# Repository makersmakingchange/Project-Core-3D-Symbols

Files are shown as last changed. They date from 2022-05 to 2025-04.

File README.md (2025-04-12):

# Project Core 3D Symbols
The Project Core 3D symbols consists of a set of 3D printable three-dimensional (3D) symbols that represent 36 words in the Universal Core vocabulary. The word category is indicated with the shape, texture, and color of the base. The individual word is indicated with a unique raised element, the printed word, and the word in Braille. This repository contains a copy of Version 4, last updated January 2020. For instructions on how to introduce and use these symbols, refer to the original site: http://www.project-core.com/3d-symbols/   

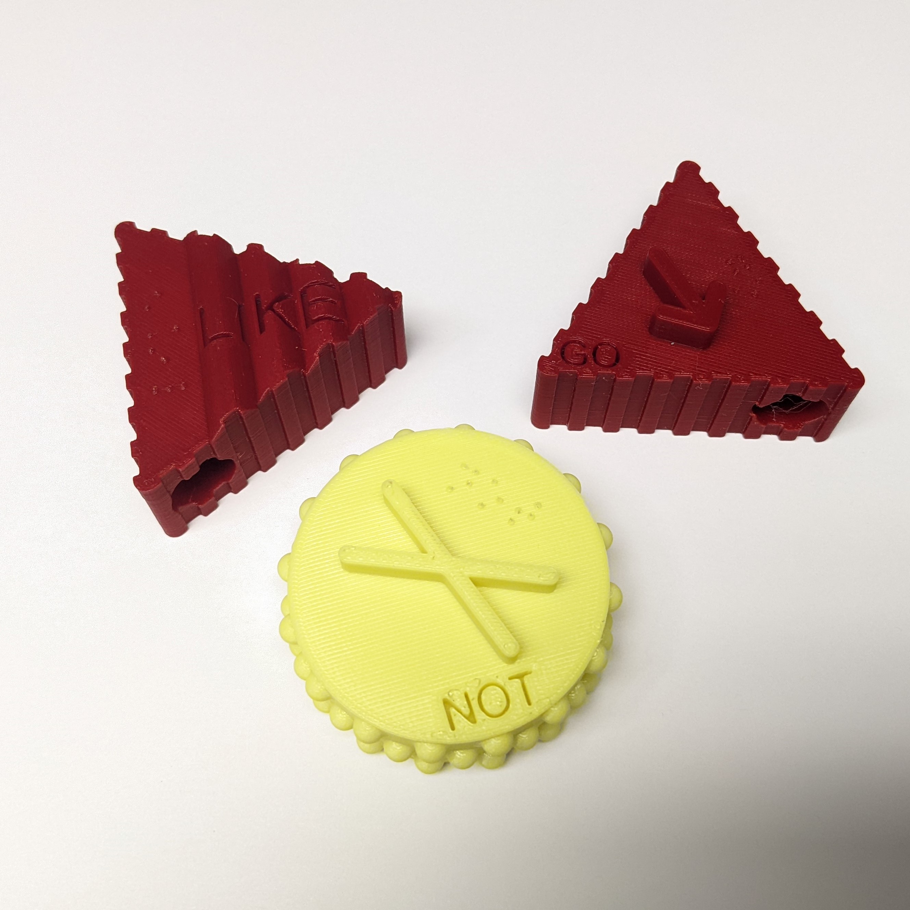
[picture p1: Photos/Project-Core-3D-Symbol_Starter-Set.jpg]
Picture of three 3D printed tactile symbols. There are three symbols, a triangular red 'Go', a triangular red 'Like', and a circular yellow 'Not'.


| **Word Class** | **Shape** | **Edge Texture** | **Color** |
|:---:|:---:|:---:|:---:|
| adverb | circle  | bumps (reverse golf ball dimples) | yellow  |
| adjective | heart | smooth | blue |
| pronoun |  hexagon  | cross hatch | white |
| preposition  | square  | horizontal grooves | green |
| verb |  triangle | vertical ridges like a quarter | red |
| noun | trapezoid | horizontal wavy grooves | orange  |
|  interjection  |  pentagon | single string of bumps (string of pearls) | black |

## More info at
- [Project Core](http://www.project-core.com/)
- [Project Core 3D Symbols](http://www.project-core.com/3d-symbols)
- [Project Core 3D Symbol - Use Instructions](http://www.project-core.com/3d-symbols-use/)
- [Makers Making Change Project Page](https://makersmakingchange.com/project/project-core-3d-symbols/)

## Getting Started

### 1. Determine which symbols are required
Refer to the usage guide and/or consult with the user to determine which of the symbols are required.

### 2. 3D Print the Symbols
All of the individual print files are in the [/Build_Files/3D_Print_Files](/Build_Files/3D_Print_Files/) folder.
Note that depending on the word class, there are 7 different intended colors of filament. The starter set (GO, LIKE, NOT) requires two filament colors: yellow and red. If printed in the intended colors, the full set of 36 requires 5 filament colors: yellow, blue, white, green, and red.

## Files
### Documentation
| Document | Version | Link |
|---|---|---|
| Bill of Materials | 1.0 | [Project-Core-3D-Symbols_Bill_of_Materials](/Documentation/Project-Core-3D-Symbols_BOM_V1.0.xlsx) |
| Maker Checklist | 1.0 | [Project-Core-3D-Symbols_Maker_Checklist](/Documentation/Project-Core-3D-Symbols_Maker_Checklist_V1.0.pdf) |
| User Guide | 09.25.17 | [Project-Core-3D-Symbols_Use](/Documentation/Project-Core-3D-Symbols_Use_09.25.17.pdf) |
| Changelog | 1.0 | [Project-Core-3D-Symbols_Changelog](/Documentation/Project-Core-3D-Symbols_Changelog_V1.0.pdf) |

### Design Files
Unfortunately, the original design files are not available for this project.

### Build Files
 - [3D Print Files](/Build_Files/3D_Print_Files)

 Note: The original filenames have been changed to the following format: WORD_COLOR_VERSION.stl. This should make it easier to print the symbols in the intended color if so desired.

## Attribution
The 3D Universal Core Vocabulary Symbols were designed by [The Center for Literacy and Disability Studies](http://www.project-core.com/3d-symbols/).

The Bill of Materials and the 3D Printing Guide were created by Neil Squire / Makers Making Change. 

## License


The 3D Universal Core Vocabulary Symbols by [The Center for Literacy and Disability Studies](https://www.project-core.com/3d-symbols/) are licensed under a [Creative Commons Attribution 4.0 International License](https://creativecommons.org/licenses/by/4.0/).

----
<!-- ABOUT MMC START -->
## About Makers Making Change
[Makers Making Change Logo](https://www.makersmakingchange.com/)

Makers Making Change is a program of [Neil Squire](https://www.neilsquire.ca/), a Canadian non-profit that uses technology, knowledge, and passion to empower people with disabilities.

Makers Making Change leverages the capacity of community based Makers, Disability Professionals and Volunteers to develop and deliver affordable Open Source Assistive Technologies.

 - Website: [www.MakersMakingChange.com](https://www.makersmakingchange.com/)
 - GitHub: [makersmakingchange](https://github.com/makersmakingchange)
 - Bluesky: [@makersmakingchange.bsky.social](https://bsky.app/profile/makersmakingchange.bsky.social)
 - Instagram: [@makersmakingchange](https://www.instagram.com/makersmakingchange)
 - Facebook: [makersmakechange](https://www.facebook.com/makersmakechange)
 - LinkedIn: [Neil Squire Society](https://www.linkedin.com/company/neil-squire-society/)
 - Thingiverse: [makersmakingchange](https://www.thingiverse.com/makersmakingchange/about)
 - Printables: [MakersMakingChange](https://www.printables.com/@MakersMakingChange)

### Contact Us
For technical questions, to get involved, or to share your experience we encourage you to [visit our website](https://www.makersmakingchange.com/) or [contact us](https://www.makersmakingchange.com/s/contact).
<!-- ABOUT MMC END -->

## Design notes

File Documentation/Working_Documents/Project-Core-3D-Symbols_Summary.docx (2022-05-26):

# Title

## Project Core 3D Symbols

## Subtitle

A set of 3d printable tactile representations of Universal Core Vocabulary

## Device Specifications

Designer: Center for Literacy and Disability Studies

Build Time: 1-4 hr

Cost: $6-$20

Stage: User Tested

Skills Required: 3D Printing

Disability Type: Visual, Cognitive/Learning

Difficulty: Beginner

Time to Complete: 1-4 hr, >10 hour

License: Attribution 4.0 International

Usage: Communication Aids (AAC)

Type: n/a

## Device Details

### Overview

The Project Core 3D symbols are a set of 3D printable three-dimensional (3D) symbols that represent words in the Universal Core vocabulary (https://www.med.unc.edu/ahs/clds/universal-core-vocabulary/). The Universal Core vocabulary is ‘a set of 36 highly useful single words that can be used alone or in combination to communicate for a range of purposes on countless topics with a wide variety of communication partners.’

For the 3D symbols, the individual word is indicated with a unique raised element, the printed word, and the word in Braille. The word category is indicated with the shape, texture, and color of the base.

Project Core also provides the symbols in different formats.

### Usage

These symbols may be useful to help students with visual impairments and/or significant cognitive impairments communicate. For instructions on how to introduce and use these symbols, refer to the original site: http://www.project-core.com/3d-symbols/

### Cost

Each symbol requires less than $1 of plastic. The cost of materials for the three starter symbols is about $1.50. A full set requires $18 worth of plastic. The total cost to produce these may be increased if the different colors are required. (A 1 kg roll of filament is typically $25-35)

### Build Instructions

Each symbol is 3D printed. The files can be found at the linked GitHub repository or on the original site.

#### Skills Required

- 3D printing

#### Time Required

Each symbol takes approximately 2 hours to 3D print on its own. A total set may then take up to 73 hours to print.

#### 3D Printing

The symbols are a simple print and do not require support. Refer to the 3D Printing Guide for instructions. Multiple symbols of the same color may be printed at the same time. The red symbols may require two setups.

### Attribution

The 3D Universal Core Vocabulary Symbols were designed by [The Center for Literacy and Disability Studies](http://www.project-core.com/3d-symbols/).

The Bill of Materials and the 3D Printing Guide were created by Neil Squire / Makers Making Change.

## Project Core 3D Symbols

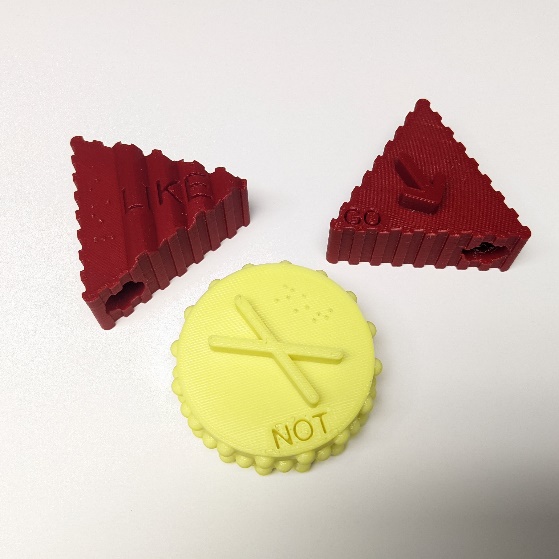
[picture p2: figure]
Picture of three 3D printed tactile symbols. There are three symbols, a triangular red "Go", a triangular red "Like", and a circular yellow "Not".

MMC Library Link:

https://makersmakingchange.com/project/project-core-3d-symbols/

### Overview

The Project Core 3D symbols are a set of 3D printable three-dimensional (3D) symbols that represent words in the Universal Core vocabulary (https://www.med.unc.edu/ahs/clds/universal-core-vocabulary/). The Universal Core vocabulary is ‘a set of 36 highly useful single words that can be used alone or in combination to communicate for a range of purposes on countless topics with a wide variety of communication partners.’

For the 3D symbols, the individual word is indicated with a unique raised element, the printed word, and the word in Braille. The word category is indicated with the shape, texture, and color of the base.

Project Core also provides the symbols in different formats.

### Usage

These symbols may be useful to help students with visual impairments and/or significant cognitive impairments communicate. For instructions on how to introduce and use these symbols, refer to the original site: http://www.project-core.com/3d-symbols/

© 2022 by Neil Squire. This work is licensed under the CC BY 4.0 License: http://creativecommons.org/licenses/by/4.0 Files available at https://makersmakingchange.com/project/project-core-3d-symbols/ Page 1 of 2

V4 | MAY 2022 Project Core 3D Symbols Summary

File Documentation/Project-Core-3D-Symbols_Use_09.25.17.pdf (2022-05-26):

The following provides initial guidance to school teams on how to introduce and use the 3D symbols. This document will continue to be revised as a result of ongoing research to further define effective practices. Please visit www.project-core.com for the latest version.

© 2016 University of North Carolina at Chapel Hill, The Center for Literacy and Disability Studies www.project-core.com
draft date: 09/25/2017

### 3D Symbol Core Sandwich – GO

First:
Recognize that an activity involves movement that can accurately be represented with GO.

Next:
Place the 3D symbol for GO in the student’s dominant hand (the side with the loop is always by the fingers, Braille faces up so the tips of the fingers can brush across).
Say the word GO.
For students who are deaf, sign an approximation of the word GO using hand-under-hand with the student’s non-dominant hand (e.g., use an upward facing open palm and move it under the student’s hand away from the body).

Sandwich (link the symbol with the known feeling of moving):
Start GO-ing and stop after a minute or so.

Then:
Remove the symbol GO from the student’s hand and place it in a designated area. Lift the student’s hand to brush across the 3D symbol for GO.
Help the student pick up and explore the GO symbol.
Say the word GO.
For students who are deaf, sign an approximation of the word GO using hand-under-hand with the student’s non-dominant hand
Place the 3D symbol for GO back in the designated area.

Last:
Tap 2x under the student’s wrist.
If the student touches the 3D symbol, respond by putting the symbol in his/her hand and GO more. If the student does not touch the 3D symbol and you need to continue GO-ing. place the
symbol in his/her hand, and say the word GO or sign GO if the student is deaf.
Then GO.

NOTE: The student is not required to use the symbol in order to go. You are teaching the association between the act of going and the 3D symbol. It may be several weeks or months before there have been enough learning opportunities for the student to use the symbol in any meaningful way.

The following provides initial guidance to school teams on how to introduce and use the 3D symbols. This document will continue to be revised as a result of ongoing research to further define effective practices. Please visit www.project-core.com for the latest version.

3D Symbol Core Sandwich- LIKE

© 2016 University of North Carolina at Chapel Hill, The Center for Literacy and Disability Studies

First:
Recognize that the student is indicating pleasure about something that is happening/present.

Next:
Place the 3D symbol for LIKE in the student’s dominant hand (the side with the loop is always by the fingers, Braille faces up so the tips of the fingers can brush across)
Say the word LIKE.
For students who are deaf, sign an approximation of the word LIKE using hand-under-hand with the student’s non-dominant hand (e.g., use hand shape for letter A, start the sign a bit out from the student’s chest with palm facing in [but not touching], then move your hand away from the body).

Sandwich (link the symbol with his/her preference or pleasure in response to an object, activity, sensory input):
Present the preferred object, activity, sensory input while helping the student move his/her dominant hand with LIKE in it.

Then:
Remove the symbol LIKE from the student’s hand and place it in a designated area. Lift the student’s hand to brush across the 3D symbol for LIKE.
Help the student pick up and explore the LIKE symbol.
Say the word LIKE.
For students who are deaf, sign an approximation of the word LIKE using hand-under-hand with the student’s non-dominant hand
Place the 3D symbol for LIKE back in the designated area.

Last:
Tap 2x under wrist.
If the student touches the LIKE symbol, respond by presenting the preferred object, activity, sensory input while helping the student move his/her dominant hand with LIKE in it.
If the student does not touch the LIKE symbol stop presenting the preferred object, activity, sensory input for a few minutes before repeating the cycle.

NOTE: The student is not required to use the symbol in order to get the preferred object, activity, or sensory. However, you will stop presenting for a few minutes and then reintroduce. You are teaching the association between the preferred things and the 3D symbol. It may be several weeks or months before there have been enough learning opportunities for the student to use the symbol in any meaningful way.

© 2016 University of North Carolina at Chapel Hill, The Center for Literacy and Disability Studies

The following provides initial guidance to school teams on how to introduce and use the 3D symbols. This document will continue to be revised as a result of ongoing research to further define effective practices. Please visit www.project-core.com for the latest version.

3D Symbol Core Sandwich - NOT
First:
Recognize that the student is indicating displeasure or refusal about something that is happening or present.

Next:
Place the 3D symbol for NOT in the student’s dominant hand (the side with the loop is always by th fingers, Braille faces up so the tips of the fingers can brush across).

e

Say the word NOT.
For students who are deaf, sign an approximation of the word GO using hand-under-hand with the student’s non-dominant hand (e.g., use hand shape for letter A, start the sign just under but touching the student’s chin with palm facing sideways, then move your hand away from the chin).

Sandwich (link the symbol with her displeasure or refusal in response to an object, activity, sensory input):
Present the object, activity, sensory input that the student is refusing while helping the student move her dominant hand with NOT in it.

Then:
Remove the symbol NOT from the student’s dominant hand and place it in the designated area. Lift the student’s hand to brush across the 3D symbol for NOT.
Help the student pick up and explore the NOT symbol.
Say the word NOT.
For students who are deaf, sign an approximation of the word NOT using hand-under-hand with the student’s non-dominant hand.
Place the 3D symbol for NOT back in the designated area.

Last:
Tap 2x under wrist.
If the student touches the NOT symbol, respond by stopping the presentation of the object, activity, or sensory input.
If the student does not touch the NOT symbol, continue to try to present the object, activity, or sensory input for a minute or so before stopping.

NOTE: The student is not required to use the symbol in order to get the object, activity or sensory input to stop. You are teaching the association between the NOT and the 3D symbol. It may be several weeks or months before there have been enough learning opportunities for the student to use the symbol in any meaningful way.

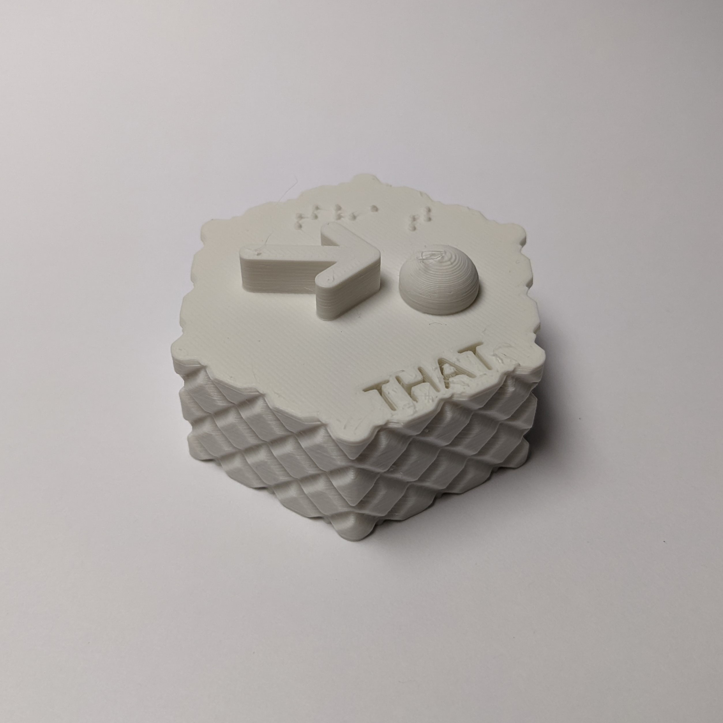
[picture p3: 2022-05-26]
Photos/Project-Core-3D-Symbol-That.jpg

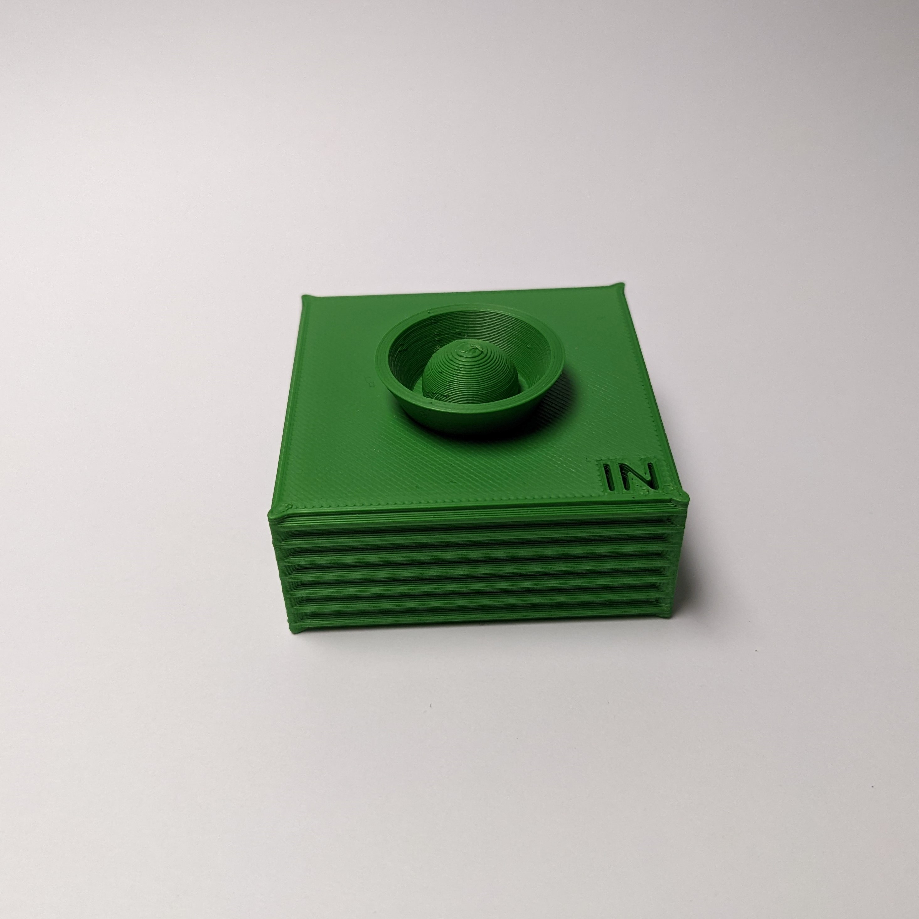
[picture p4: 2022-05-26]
Photos/Project-Core-3D-Symbol-In.jpg

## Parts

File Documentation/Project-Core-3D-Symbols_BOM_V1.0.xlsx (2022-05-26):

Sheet: BOM
Project Core 3D Symbols |  |  | Total Cost | Total Print time (hr) | Total filament (g)
Version: V4 | Date Created: 2022-05-19 |  | $17.29 | 73.15 | 730.6727 |  | $1.51
3D Printed Parts ESTIMATED PRICING USING 1KG ROLL COST: | $25.00
Part | Description | Filament Type | QTY | TOTAL Mass (g) | Estimated Price | Print Time (h:m) | Filename | Print Time (m)
All | Blue | 1 | 1 | 21.7981 | $0.54 | 2h3m | all_blue_v4 | 123 | all_blue_v4 | 2h3m | 21.7981 | Blue
Can | Red | 3 | 1 | 17.3127 | $0.43 | 1h51m | can_red_v4 | 111 | can_red_v4 | 1h51m | 17.3127 | Red
Different | Blue | 1 | 1 | 20.7009 | $0.52 | 1h57m | different_blue_v4 | 117 | different_blue_v4 | 1h57m | 20.7009 | Blue
Do | Red | 3 | 1 | 19.2282 | $0.48 | 1h56m | do_red_v4 | 116 | do_red_v4 | 1h56m | 19.2282 | Red
Finished | Blue | 1 | 1 | 20.6912 | $0.52 | 1h56m | finish_blue_v4 | 116 | finish_blue_v4 | 1h56m | 20.6912 | Blue
Get | Red | 3 | 1 | 17.3308 | $0.43 | 1h51m | get_red_v4 | 111 | get_red_v4 | 1h51m | 17.3308 | Red
Go | Blue | 3 | 1 | 20.3017 | $0.51 | 1h51m | good_blue_v4 | 111 | good_blue_v4 | 1h51m | 20.3017 | Red
Good | Blue | 1 | 1 | 17.0704 | $0.43 | 1h49m | go_red_v4 | 109 | go_red_v4 | 1h49m | 17.0704 | Blue
He | White | 4 | 1 | 17.3355 | $0.43 | 1h53m | help_red_v4 | 113 | help_red_v4 | 1h53m | 17.3355 | White
Help | Red | 3 | 1 | 21.7796 | $0.54 | 2h6m | here_yellow_v4 | 126 | here_yellow_v4 | 2h6m | 21.7796 | Red
Here | Yellow | 5 | 1 | 20.9239 | $0.52 | 2h13m | he_white_v4 | 133 | he_white_v4 | 2h13m | 20.9239 | Yellow
I | White | 4 | 1 | 24.866 | $0.62 | 2h14m | in_green_v4 | 134 | in_green_v4 | 2h14m | 24.866 | White
In | Green | 2 | 1 | 20.9877 | $0.52 | 2h12m | it_white_v4 | 132 | it_white_v4 | 2h12m | 20.9877 | Green
It | White | 4 | 1 | 19.9683 | $0.50 | 2h5m | i_white_v4 | 125 | i_white_v4 | 2h5m | 19.9683 | White
Like | Red | 3 | 1 | 18.2607 | $0.46 | 1h57m | like_red_v4 | 117 | like_red_v4 | 1h57m | 18.2607 | Red
Look | Red | 3 | 1 | 17.4701 | $0.44 | 1h51m | look_red_v4 | 111 | look_red_v4 | 1h51m | 17.4701 | Red
Make | Red | 3 | 1 | 17.4861 | $0.44 | 1h53m | make_red_v4 | 113 | make_red_v4 | 1h53m | 17.4861 | Red
More | Yellow | 5 | 1 | 21.2902 | $0.53 | 2h4m | more_yellow_v4 | 124 | more_yellow_v4 | 2h4m | 21.2902 | Yellow
Not | Yellow | 5 | 1 | 21.7937 | $0.54 | 2h3m | not_yellow_v4 | 123 | not_yellow_v4 | 2h3m | 21.7937 | Yellow
On | Green | 2 | 1 | 24.7259 | $0.62 | 2h18m | on_green_v4 | 138 | on_green_v4 | 2h18m | 24.7259 | Green
Open | Red | 3 | 1 | 18.3082 | $0.46 | 1h56m | open_red_v4 | 116 | open_red_v4 | 1h56m | 18.3082 | Red
Put | Red | 3 | 1 | 17.4667 | $0.44 | 1h51m | put_red_v4 | 111 | put_red_v4 | 1h51m | 17.4667 | Red
Same | Blue | 1 | 1 | 20.4522 | $0.51 | 1h52m | same_blue_v4 | 112 | same_blue_v4 | 1h52m | 20.4522 | Blue
She | White | 4 | 1 | 20.9259 | $0.52 | 2h14m | she_white_v4 | 134 | she_white_v4 | 2h14m | 20.9259 | White
Some | Yellow | 5 | 1 | 23.3515 | $0.58 | 2h22m | some_yellow_v4 | 142 | some_yellow_v4 | 2h22m | 23.3515 | Yellow
Stop | Red | 3 | 1 | 17.4447 | $0.44 | 1h52m | stop_red_v4 | 112 | stop_red_v4 | 1h52m | 17.4447 | Red
That | White | 4 | 1 | 21.1536 | $0.53 | 2h16m | that_white_v4 | 136 | that_white_v4 | 2h16m | 21.1536 | White
Turn | Red | 3 | 1 | 17.3083 | $0.43 | 1h51m | turn_red_v4 | 111 | turn_red_v4 | 1h51m | 17.3083 | Red
Up | Green | 2 | 1 | 24.2116 | $0.61 | 2h13m | up_green_v4 | 133 | up_green_v4 | 2h13m | 24.2116 | Green
Want | Red | 3 | 1 | 17.2899 | $0.43 | 1h52m | want_red_v4 | 112 | want_red_v4 | 1h52m | 17.2899 | Red
What | Yellow | 5 | 1 | 21.7549 | $0.54 | 2h6m | what_yellow_v4 | 126 | what_yellow_v4 | 2h6m | 21.7549 | Yellow
When | Yellow | 5 | 1 | 22.6626 | $0.57 | 2h9m | when_yellow_v4 | 129 | when_yellow_v4 | 2h9m | 22.6626 | Yellow
Where | Yellow | 5 | 1 | 22.107 | $0.55 | 2h9m | where_yellow_v4 | 129 | where_yellow_v4 | 2h9m | 22.107 | Yellow
Who | Yellow | 5 | 1 | 22.3146 | $0.56 | 2h6m | who_yellow_v4 | 126 | who_yellow_v4 | 2h6m | 22.3146 | Yellow
Why | Yellow | 5 | 1 | 21.9828 | $0.55 | 2h5m | why_yellow_v4 | 125 | why_yellow_v4 | 2h5m | 21.9828 | Yellow
You | White | 4 | 1 | 20.6165 | $0.52 | 2h12m | you_white_v4 | 132 | you_white_v4 | 2h12m | 20.6165 | White
 |  |  |  | Total Print Cost: | $17.29
Tools for Assembly
<None>
Alternatives (if there are other sources for some parts link them below)
Part and description | Link
<n/a>
Filament | Material | Colour
1 | PLA | Blue |  |  | $25.00
2 | PLA | Green |  |  | $25.00
3 | PLA | Red |  |  | $25.00
4 | PLA | White |  |  | $25.00
5 | PLA | Yellow |  |  | $25.00
 |  |  |  |  | $125.00

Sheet: 3DPrints
File | Qty | Time | Mass | Infill | Support | Nozzle | Layer | Material | Notes | Color | Time | Time (Minutes)
all_blue_v4 | 1 | 2:03:00 | 21.7981 | 15-20 | No | 0.4 | 0.2 | PLA |  | Blue | 2h3m | 123
different_blue_v4 | 1 | 1:57:00 | 20.7009 | 15-20 | No | 0.4 | 0.2 | PLA |  | Blue | 1h57m | 117
finish_blue_v4 | 1 | 1:56:00 | 20.6912 | 15-20 | No | 0.4 | 0.2 | PLA |  | Blue | 1h56m | 116
good_blue_v4 | 1 | 1:51:00 | 20.3017 | 15-20 | No | 0.4 | 0.2 | PLA |  | Blue | 1h51m | 111
same_blue_v4 | 1 | 1:52:00 | 20.4522 | 15-20 | No | 0.4 | 0.2 | PLA |  | Blue | 1h52m | 112
in_green_v4 | 1 | 2:14:00 | 24.866 | 15-20 | No | 0.4 | 0.2 | PLA |  | Green | 2h14m | 134
on_green_v4 | 1 | 2:18:00 | 24.7259 | 15-20 | No | 0.4 | 0.2 | PLA |  | Green | 2h18m | 138
up_green_v4 | 1 | 2:13:00 | 24.2116 | 15-20 | No | 0.4 | 0.2 | PLA |  | Green | 2h13m | 133
can_red_v4 | 1 | 1:51:00 | 17.3127 | 15-20 | No | 0.4 | 0.2 | PLA |  | Red | 1h51m | 111
do_red_v4 | 1 | 1:56:00 | 19.2282 | 15-20 | No | 0.4 | 0.2 | PLA |  | Red | 1h56m | 116
get_red_v4 | 1 | 1:51:00 | 17.3308 | 15-20 | No | 0.4 | 0.2 | PLA |  | Red | 1h51m | 111
go_red_v4 | 1 | 1:49:00 | 17.0704 | 15-20 | No | 0.4 | 0.2 | PLA | Starter Set | Red | 1h49m | 109
help_red_v4 | 1 | 1:53:00 | 17.3355 | 15-20 | No | 0.4 | 0.2 | PLA |  | Red | 1h53m | 113
like_red_v4 | 1 | 1:57:00 | 18.2607 | 15-20 | No | 0.4 | 0.2 | PLA | Starter Set | Red | 1h57m | 117
look_red_v4 | 1 | 1:51:00 | 17.4701 | 15-20 | No | 0.4 | 0.2 | PLA |  | Red | 1h51m | 111
make_red_v4 | 1 | 1:53:00 | 17.4861 | 15-20 | No | 0.4 | 0.2 | PLA |  | Red | 1h53m | 113
open_red_v4 | 1 | 1:56:00 | 18.3082 | 15-20 | No | 0.4 | 0.2 | PLA |  | Red | 1h56m | 116
put_red_v4 | 1 | 1:51:00 | 17.4667 | 15-20 | No | 0.4 | 0.2 | PLA |  | Red | 1h51m | 111
stop_red_v4 | 1 | 1:52:00 | 17.4447 | 15-20 | No | 0.4 | 0.2 | PLA |  | Red | 1h52m | 112
turn_red_v4 | 1 | 1:51:00 | 17.3083 | 15-20 | No | 0.4 | 0.2 | PLA |  | Red | 1h51m | 111
want_red_v4 | 1 | 1:52:00 | 17.2899 | 15-20 | No | 0.4 | 0.2 | PLA |  | Red | 1h52m | 112
he_white_v4 | 1 | 2:13:00 | 20.9239 | 15-20 | No | 0.4 | 0.2 | PLA |  | White | 2h13m | 133
i_white_v4 | 1 | 2:05:00 | 19.9683 | 15-20 | No | 0.4 | 0.2 | PLA |  | White | 2h5m | 125
it_white_v4 | 1 | 2:12:00 | 20.9877 | 15-20 | No | 0.4 | 0.2 | PLA |  | White | 2h12m | 132
she_white_v4 | 1 | 2:14:00 | 20.9259 | 15-20 | No | 0.4 | 0.2 | PLA |  | White | 2h14m | 134
that_white_v4 | 1 | 2:16:00 | 21.1536 | 15-20 | No | 0.4 | 0.2 | PLA |  | White | 2h16m | 136
you_white_v4 | 1 | 2:12:00 | 20.6165 | 15-20 | No | 0.4 | 0.2 | PLA |  | White | 2h12m | 132
here_yellow_v4 | 1 | 2:06:00 | 21.7796 | 15-20 | No | 0.4 | 0.2 | PLA |  | Yellow | 2h6m | 126
more_yellow_v4 | 1 | 2:04:00 | 21.2902 | 15-20 | No | 0.4 | 0.2 | PLA |  | Yellow | 2h4m | 124
not_yellow_v4 | 1 | 2:03:00 | 21.7937 | 15-20 | No | 0.4 | 0.2 | PLA | Starter Set | Yellow | 2h3m | 123
some_yellow_v4 | 1 | 2:22:00 | 23.3515 | 15-20 | No | 0.4 | 0.2 | PLA |  | Yellow | 2h22m | 142
what_yellow_v4 | 1 | 2:06:00 | 21.7549 | 15-20 | No | 0.4 | 0.2 | PLA |  | Yellow | 2h6m | 126
when_yellow_v4 | 1 | 2:09:00 | 22.6626 | 15-20 | No | 0.4 | 0.2 | PLA |  | Yellow | 2h9m | 129
where_yellow_v4 | 1 | 2:09:00 | 22.107 | 15-20 | No | 0.4 | 0.2 | PLA |  | Yellow | 2h9m | 129
who_yellow_v4 | 1 | 2:06:00 | 22.3146 | 15-20 | No | 0.4 | 0.2 | PLA |  | Yellow | 2h6m | 126
why_yellow_v4 | 1 | 2:05:00 | 21.9828 | 15-20 | No | 0.4 | 0.2 | PLA |  | Yellow | 2h5m | 125

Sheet: FilamentColor
Row Labels | Sum of TOTAL Mass (g) | Sum of Print Time (m) | Sum of Quantity Needed
Blue | 100.7128 | 577 | 5
Green | 69.9252 | 403 | 3
Red | 236.9877 | 1478 | 13
White | 124.8658 | 774 | 6
Yellow | 198.1812 | 1157 | 9
Grand Total | 730.6727 | 4389 | 36

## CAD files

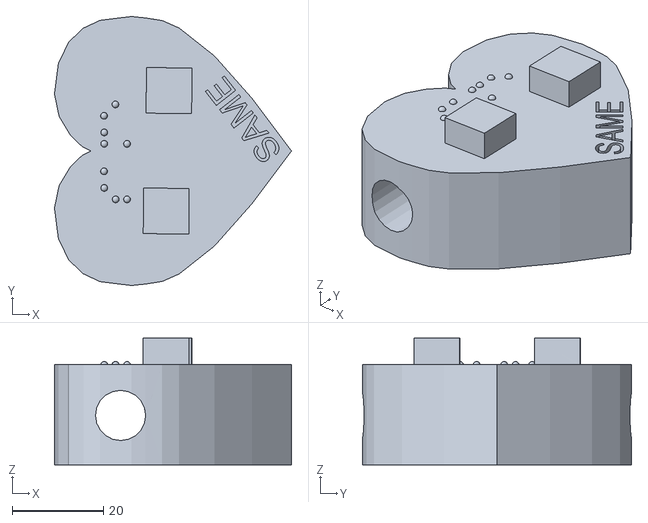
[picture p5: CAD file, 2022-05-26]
Build_Files/3D_Print_Files/By_Color/Blue-Adjective/same_blue_v4.stl
52.0 x 59.0 x 27.8

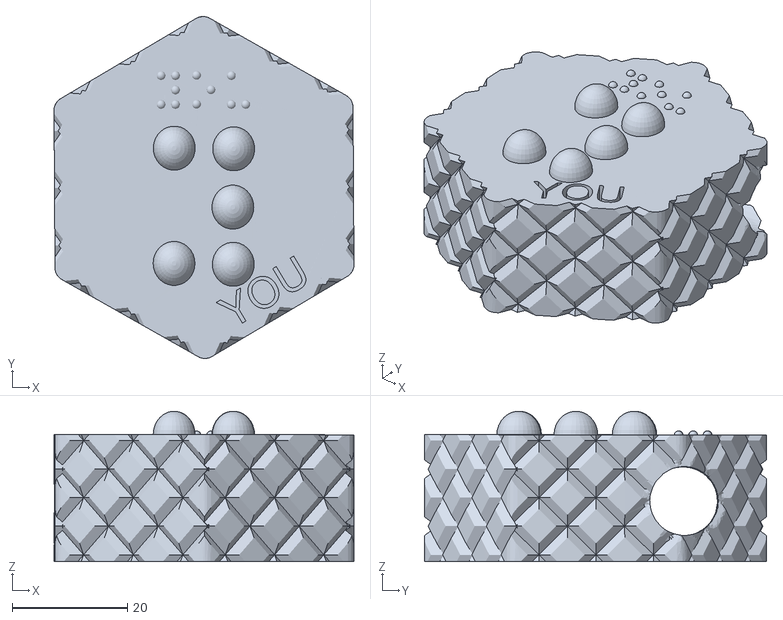
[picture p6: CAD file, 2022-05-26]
Build_Files/3D_Print_Files/By_Color/White-Pronoun/you_white_v4.stl
52.0 x 59.2 x 26.0

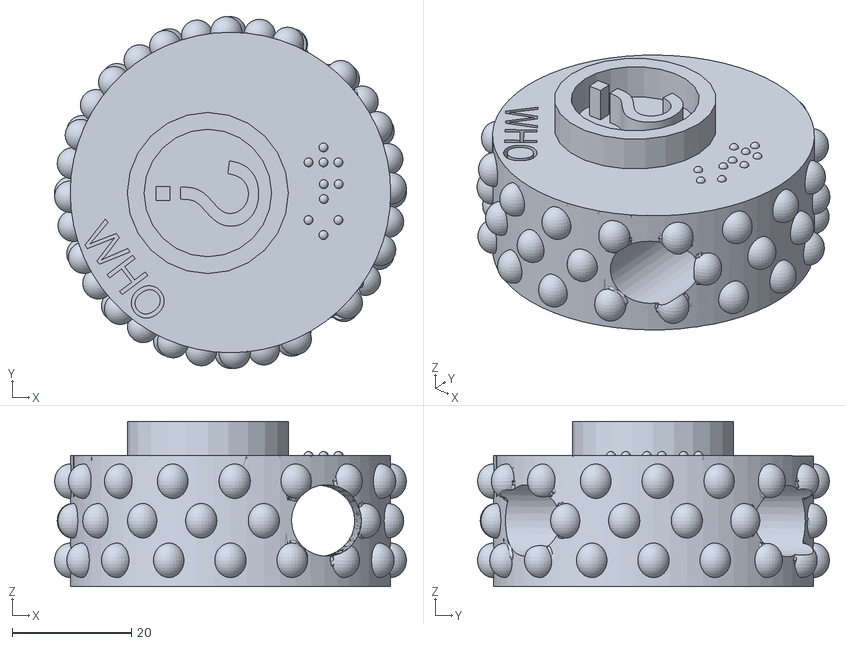
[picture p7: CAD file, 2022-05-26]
Build_Files/3D_Print_Files/By_Color/Yellow-Adverb/who_yellow_v4.stl
59.0 x 59.0 x 27.7

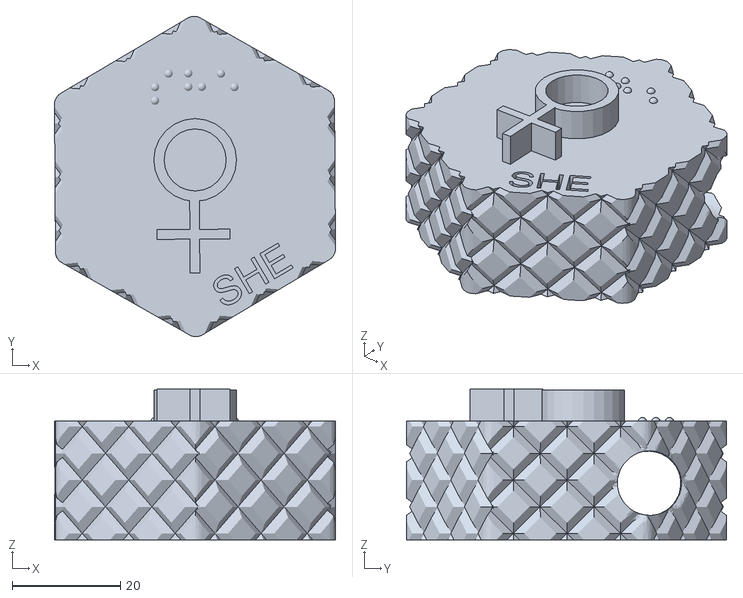
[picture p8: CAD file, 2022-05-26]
Build_Files/3D_Print_Files/By_Color/White-Pronoun/she_white_v4.stl
52.0 x 59.2 x 27.9

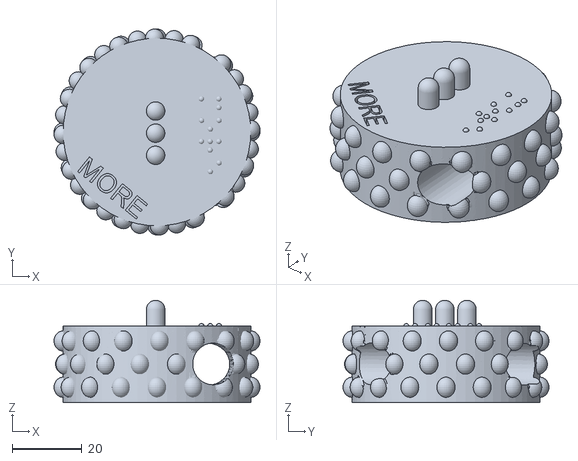
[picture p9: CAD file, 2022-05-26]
Build_Files/3D_Print_Files/more_yellow_v4.stl
59.0 x 59.0 x 29.3

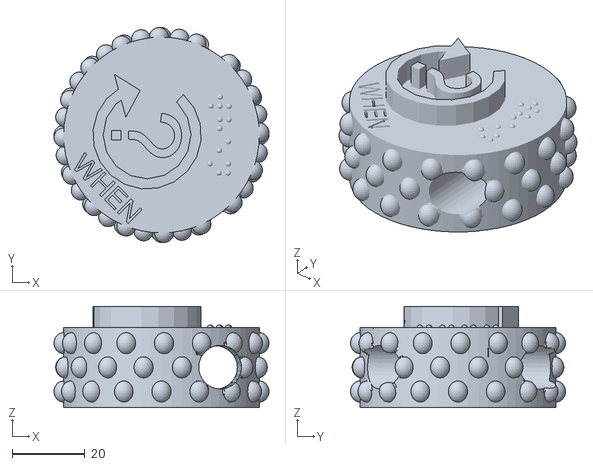
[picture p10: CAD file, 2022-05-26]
Build_Files/3D_Print_Files/By_Color/Yellow-Adverb/when_yellow_v4.stl
59.0 x 59.0 x 27.8

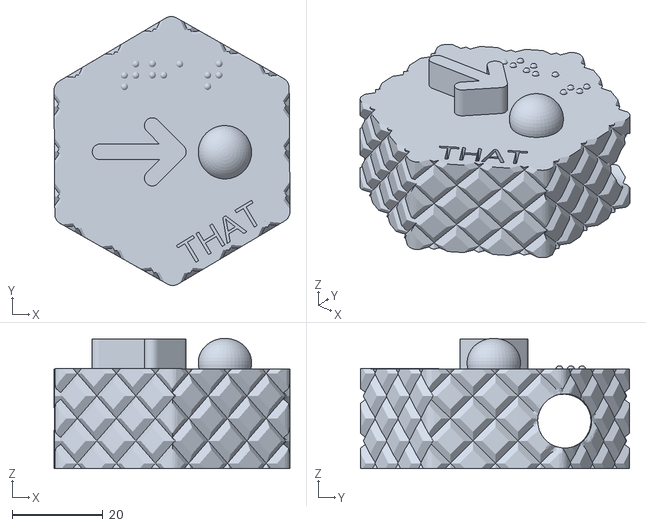
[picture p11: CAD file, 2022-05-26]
Build_Files/3D_Print_Files/By_Color/White-Pronoun/that_white_v4.stl
52.0 x 59.2 x 28.7

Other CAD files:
Build_Files/3D_Print_Files/By_Color/Blue-Adjective/good_blue_v4.stl
Build_Files/3D_Print_Files/By_Color/Yellow-Adverb/what_yellow_v4.stl
Build_Files/3D_Print_Files/By_Color/Blue-Adjective/finish_blue_v4.stl
Build_Files/3D_Print_Files/By_Color/White-Pronoun/i_white_v4.stl
Build_Files/3D_Print_Files/By_Color/Yellow-Adverb/why_yellow_v4.stl
Build_Files/3D_Print_Files/good_blue_v4.stl
Build_Files/3D_Print_Files/By_Color/Blue-Adjective/different_blue_v4.stl
Build_Files/3D_Print_Files/By_Color/White-Pronoun/it_white_v4.stl
Build_Files/3D_Print_Files/he_white_v4.stl
Build_Files/3D_Print_Files/By_Color/Yellow-Adverb/not_yellow_v4.stl
Build_Files/3D_Print_Files/By_Color/White-Pronoun/he_white_v4.stl
Build_Files/3D_Print_Files/By_Color/Yellow-Adverb/here_yellow_v4.stl
Build_Files/3D_Print_Files/By_Color/Yellow-Adverb/where_yellow_v4.stl
Build_Files/3D_Print_Files/different_blue_v4.stl
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

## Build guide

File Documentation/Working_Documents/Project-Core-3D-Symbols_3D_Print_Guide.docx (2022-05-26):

# 3D Printing Summary

Metrics | Starter Set | Full Set
Total Print Time (hr:min) | 6:49 | 73:09
Total Number of Components | 3 | 36
Typical Total Mass (g) | 57 | 731
Typical Number of Print Setups | 2 | 6
Filament Types | 2 | 5

# 3D Printing Settings

0.4 mm Nozzle – 0.2 mm Layer Height

Material | Print File Name | Qty | Total Print Time (hr:min) | Mass (g) | Infill (%) | Support (Y/N) | Notes
Blue PLA
| all_blue_v4 | 1 | 2:03 | 22 | 15-20 | No
| different_blue_v4 | 1 | 1:57 | 21 | 15-20 | No
| finish_blue_v4 | 1 | 1:56 | 21 | 15-20 | No
| good_blue_v4 | 1 | 1:51 | 20 | 15-20 | No
| same_blue_v4 | 1 | 1:52 | 20 | 15-20 | No
Green PLA
| in_green_v4 | 1 | 2:14 | 25 | 15-20 | No
| on_green_v4 | 1 | 2:18 | 25 | 15-20 | No
| up_green_v4 | 1 | 2:13 | 24 | 15-20 | No
Red PLA
| can_red_v4 | 1 | 1:51 | 17 | 15-20 | No
| do_red_v4 | 1 | 1:56 | 19 | 15-20 | No
| get_red_v4 | 1 | 1:51 | 17 | 15-20 | No
| go_red_v4 | 1 | 1:49 | 17 | 15-20 | No | Starter Set
| help_red_v4 | 1 | 1:53 | 17 | 15-20 | No
| like_red_v4 | 1 | 1:57 | 18 | 15-20 | No | Starter Set
| look_red_v4 | 1 | 1:51 | 17 | 15-20 | No
| make_red_v4 | 1 | 1:53 | 17 | 15-20 | No
| open_red_v4 | 1 | 1:56 | 18 | 15-20 | No
| put_red_v4 | 1 | 1:51 | 17 | 15-20 | No
| stop_red_v4 | 1 | 1:52 | 17 | 15-20 | No
| turn_red_v4 | 1 | 1:51 | 17 | 15-20 | No
| want_red_v4 | 1 | 1:52 | 17 | 15-20 | No
White PLA
| he_white_v4 | 1 | 2:13 | 21 | 15-20 | No
| i_white_v4 | 1 | 2:05 | 20 | 15-20 | No
| it_white_v4 | 1 | 2:12 | 21 | 15-20 | No
| she_white_v4 | 1 | 2:14 | 21 | 15-20 | No
| that_white_v4 | 1 | 2:16 | 21 | 15-20 | No
| you_white_v4 | 1 | 2:12 | 21 | 15-20 | No
Yellow PLA
| here_yellow_v4 | 1 | 2:06 | 22 | 15-20 | No
| more_yellow_v4 | 1 | 2:04 | 21 | 15-20 | No
| not_yellow_v4 | 1 | 2:03 | 22 | 15-20 | No | Starter Set
| some_yellow_v4 | 1 | 2:22 | 23 | 15-20 | No
| what_yellow_v4 | 1 | 2:06 | 22 | 15-20 | No
| when_yellow_v4 | 1 | 2:09 | 23 | 15-20 | No
| where_yellow_v4 | 1 | 2:09 | 22 | 15-20 | No
| who_yellow_v4 | 1 | 2:06 | 22 | 15-20 | No
| why_yellow_v4 | 1 | 2:05 | 22 | 15-20 | No

# Post-Processing

- Remove any strings or burrs

# Customization Options

- There aren’t any customization options for these designs.

© 2022 by Neil Squire / Makers Making Change. This work is licensed under the CC BY SA 4.0 License: http://creativecommons.org/licenses/by-sa/4.0 Files available at https://makersmakingchange.com/project/project-core-3d-symbols/ Page 1 of 2

V4 | MAY 2022 Project Core 3D Symbols 3D Printing Guide

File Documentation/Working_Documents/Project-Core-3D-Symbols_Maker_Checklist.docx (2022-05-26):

# Maker To Do List

- Talk to User about what symbols to use and whether they require different colors
- 3D Print the desired symbols

# Items to Give to User

- Printed Symbols

© 2022 by Neil Squire / Makers Making Change This work is licensed under the CC BY SA 4.0 License: http://creativecommons.org/licenses/by-sa/4.0 Files available at https://makersmakingchange.com/project/project-core-3d-symbols/ Page 1 of 1

V1.0 | MAY 2022 Project Core 3D Symbols Maker Checklist

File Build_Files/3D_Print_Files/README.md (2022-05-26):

# Project Core 3D Symbols - 3D Print Files
This folder contains the 36 symbols. For convenience, there is also copies of the files divided by intended print color.

| **Word**  | **Color** | | **Word**  | **Color** |
|---|---|:-:|---|---|
| All | Blue | | All | Blue |
| Can | Red | | Different | Blue |
| Different | Blue | | Finished  | Blue |
| Do | Red | | Good | Blue |
| Finished  | Blue | | Same | Blue |
| Get | Red | | In | Green |
| Go | Red | | On | Green |
| Good | Blue | | Up | Green |
| He | White | | Can | Red |
| Help | Red | | Do | Red |
| Here | Yellow | | Get | Red |
| I | White | | Go | Red |
| In | Green | | Help | Red |
| It | White | | Like | Red |
| Like | Red | | Look | Red |
| Look | Red | | Make | Red |
| Make | Red | | Open | Red |
| More | Yellow | | Put | Red |
| Not | Yellow | | Stop | Red |
| On | Green | | Turn | Red |
| Open | Red | | Want | Red |
| Put | Red | | He | White |
| Same | Blue | | I | White |
| She | White | | It | White |
| Some | Yellow | | She | White |
| Stop | Red | | That | White |
| That | White | | You | White |
| Turn | Red | | Here | Yellow |
| Up | Green | | More | Yellow |
| Want | Red | | Not | Yellow |
| What | Yellow | | Some | Yellow |
| When | Yellow | | What | Yellow |
| Where | Yellow | | When | Yellow |
| Who | Yellow | | Where | Yellow |
| Why | Yellow | | Who | Yellow |
| You | White | | Why | Yellow |

Filament Colours
| Colours | TOTAL Mass (g) | TOTAL Print Time (min) | Symbols  |
|---|---|---|---|
| Blue | 101 | 577 | 5 |
| Green | 70 | 403 | 3 |
| Red | 237 | 1478 | 13 |
| White | 125 | 774 | 6 |
| Yellow | 198 | 1157 | 9 |
| Grand Total | 731 | 4389 | 36 |

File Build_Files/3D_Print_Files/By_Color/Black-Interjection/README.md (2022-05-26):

# Project Core 3D Symbols
(There are no black coloured symbols (interjections) as part of the 36 words in the Universal Core vocabulary)

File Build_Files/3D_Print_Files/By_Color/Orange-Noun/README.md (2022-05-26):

# Project Core 3D Symbols
(There are no orange coloured symbols (nouns) as part of the 36 words in the Universal Core vocabulary)

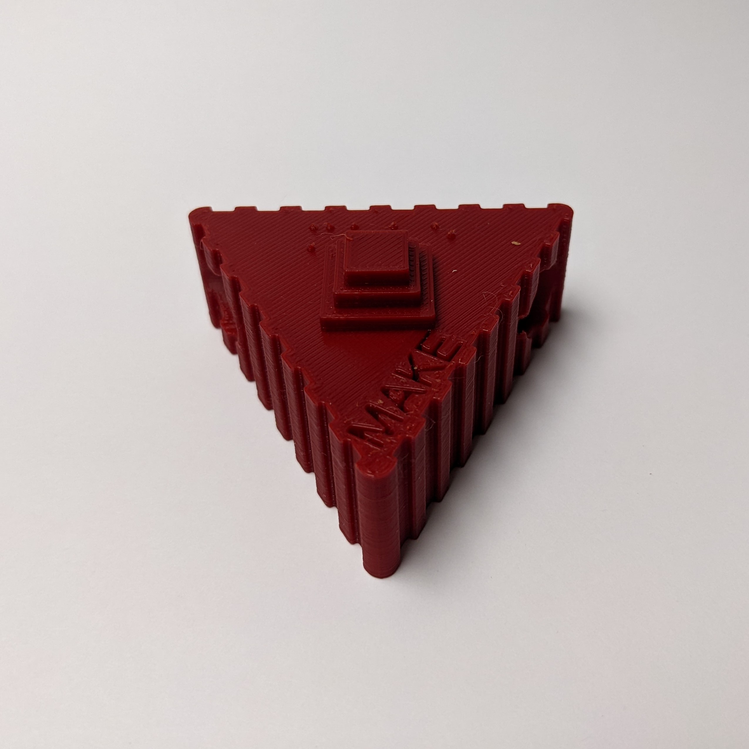
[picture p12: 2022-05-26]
Photos/Project-Core-3D-Symbol-Make.jpg

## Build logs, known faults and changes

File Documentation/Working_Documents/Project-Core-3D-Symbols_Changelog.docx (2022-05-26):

# Version 1.0 | Date 2022-May-05

- Created and populated repository on GitHub
- Organized stl files
- Changed stl file naming to include color
- Created 3D Print Guide
- Created Maker Checklist

© 2022 by Neil Squire / Makers Making Change. This work is licensed under the CC BY SA 4.0 License: http://creativecommons.org/licenses/by-sa/4.0 Files available at https://makersmakingchange.com/project/project-core-3d-symbols/ Page 1 of 1

V1.0 | MAY 2022 Project Core 3D Symbols changelog

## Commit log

2022-05-26 Add working documentation
    Add initial docs
    [Project-Core-3D-Symbols_BOM.xlsx]
2022-05-26 Add pdfs
    Add initial documentation pdfs
    [Project-Core-3D-Symbols_BOM_V1.0.xlsx]
2022-05-26 Add stls
    Add 3d printing files
    [different_blue_v4.stl, finish_blue_v4.stl, good_blue_v4.stl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]
